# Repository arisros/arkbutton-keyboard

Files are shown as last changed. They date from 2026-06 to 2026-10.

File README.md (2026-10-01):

# ArkButton: split keyboard build

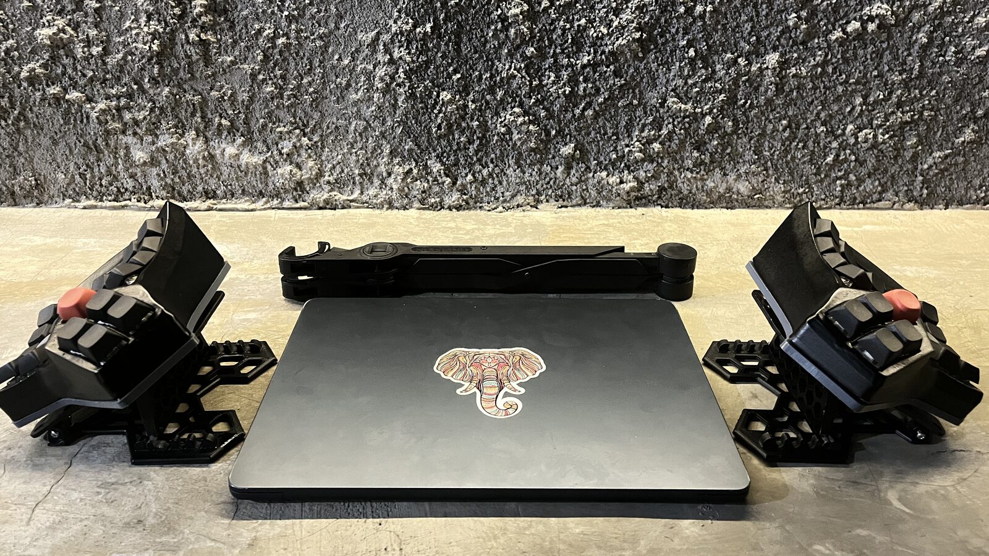
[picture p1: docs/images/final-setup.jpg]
ArkButton on its tenting stands, one half either side of a laptop


Working files for a **handwired wireless split keyboard**: Bastard Keyboards
*Scylla* / *Charybdis* geometry, 24 finger keys + 5 thumb keys per hand
(**58 keys**, the innermost thumb position stays unpopulated), 2× HwThinker Pro
Micro nRF52840 (nice!nano v2 compatible) running ZMK, printed on an Elegoo
Neptune 4 Pro, on an articulated tenting stand.

**Status:** finished in July 2026. The story with photos is in
[`docs/BUILD-LOG.md`](docs/BUILD-LOG.md).

Everything here is **source and notes**. The STL / GCODE / PNG / UF2 output is
deliberately not committed, it is regenerated (see below).

## Specs

| | |
|---|---|
| Keys | 58: 24 finger + 5 thumb per hand |
| Case | Bastard Keyboards Scylla MK2, 5-thumb default, PLA |
| Switches / keycaps | Gateron G Pro Brown, PBT MOA |
| Wiring | handwired matrix, one 1N4148 per switch, soldered direct (no hotswap) |
| Controllers | 2× HwThinker Pro Micro nRF52840 (nice!nano v2 compatible) |
| Firmware | ZMK, config in [arisros/charybdis-wireless-zmk](https://github.com/arisros/charybdis-wireless-zmk) |
| Tenting | Charybdis tenting stand mod (base stand, no wrist pads), 17/21/25/29° notches |
| Printer | Elegoo Neptune 4 Pro (Klipper) |

## Build

<p>
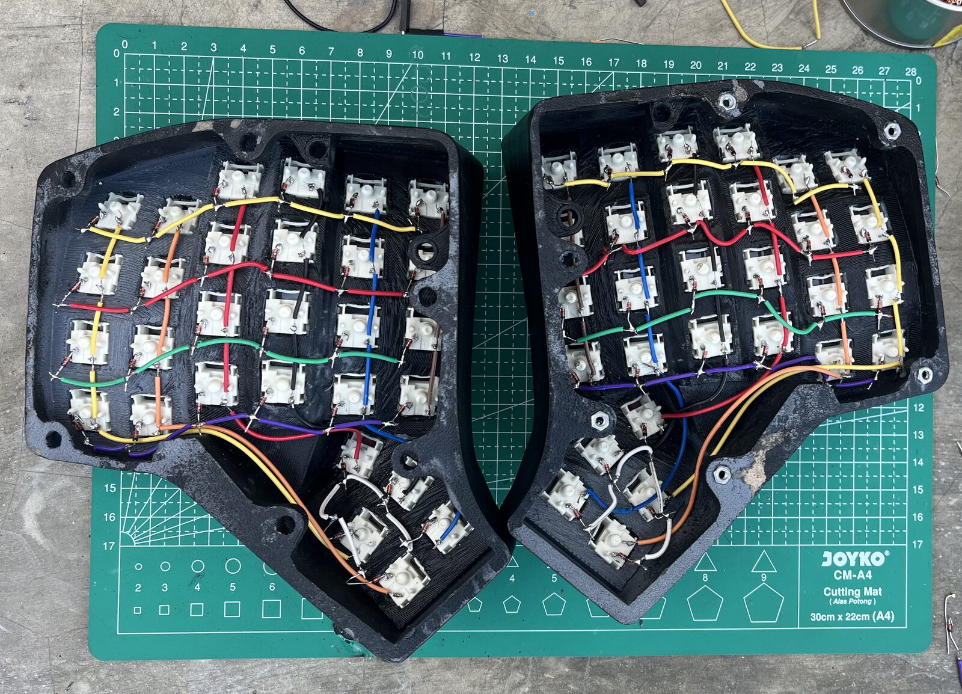
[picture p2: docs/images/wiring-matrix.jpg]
Both halves with the diode matrix wired
  
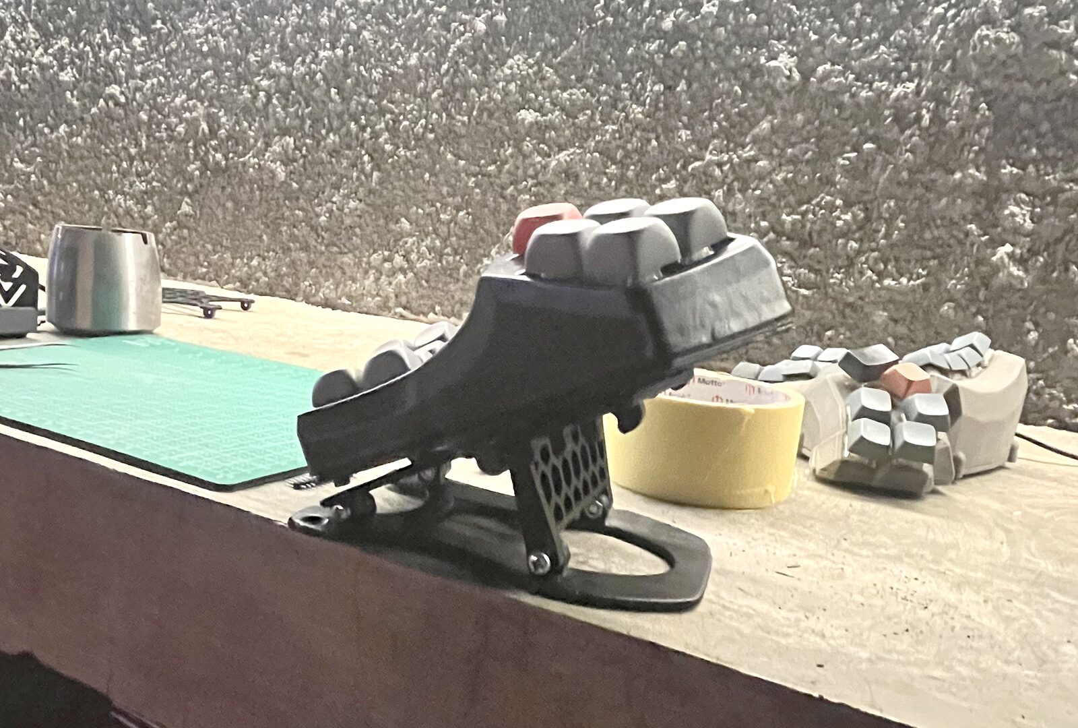
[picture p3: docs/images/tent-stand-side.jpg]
One half on the tenting stand, side view
  
</p>

More photos and the timeline: [`docs/BUILD-LOG.md`](docs/BUILD-LOG.md).

## Layout

| Path | What |
|---|---|
| `docs/` | `BUILD-LOG.md` (dated build timeline) and `images/` (build photos) |
| `PRINT-QUEUE.md` | what to print, in what order, which slicer profile. Includes the verified handedness correction (upstream file names are mirrored) |
| `SHOPPING-LIST.md` / `.csv` | parts, decisions (solder-direct, no hotswap) and what's already bought |
| `preview-*.html` | three.js viewers: `preview.html` (Charybdis 6-thumb + tenting), `preview-tenting.html` (stand + articulated arm), `preview-full-assembly-magnet.html`, `preview-wiring.html` (wiring sheet), `preview-keymap.html` (keymap) |
| `tools/` | the dev-cycle toolkit: build → validate → capture. See `tools/README.md` |
| `tools/tent/` | OpenSCAD sources for the tenting plate / cover / hinge / magnet mount, plus `PRINT-FINDINGS.md` (why the plate must print vertically) |
| `cosmos/` | OpenSCAD sources + viewers for the earlier Cosmos/Dactyl case and its I/O block |
| `firmware/` | `flash` (drop a .uf2 on a nice!nano) and `kbstatus` (Bluetooth state on macOS) |
| `upstream-mods/` | our own sources that live *inside* the gitignored upstream clones, see `upstream-mods/README.md` |

## Setup

The upstream repos are not vendored here (each has its own remote), but the tools
and viewers reference them by path. Restore them with:

```bash
tools/fetch-upstream.sh      # clones Charybdis, Scylla, Cosmos-Keyboards,
                             # dactyl-manuform-keyboard, STL-to-OpenSCAD-Converter
                             # at their pinned commits, then copies upstream-mods/ in
```

Then the normal loop (details in `tools/README.md`):

```bash
node tools/cycle.mjs <target>    # build → validate → capture → summary
node tools/capture.mjs <set…>    # headless multi-view PNGs into tools/captures/
```

If you edit anything *inside* a clone, run `tools/save-mods.sh` before committing,
otherwise the change only exists on this machine.

## Firmware

The ZMK config lives in its own repo: **https://github.com/arisros/charybdis-wireless-zmk**.
Its GitHub Actions build produces the `.uf2` files; download the `firmware` artifact,
unzip into `firmware/`, then:

```bash
firmware/flash left | right | reset
firmware/kbstatus
```

## Not in git

`*.stl` `*.3mf` `*.gcode` `*.uf2`, `out/`, `tools/captures/`, render PNGs, the
upstream clones, and `node_modules/`. All of it is regenerated from what *is* here.

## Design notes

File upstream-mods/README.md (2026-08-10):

# upstream-mods

Source files of *ours* that physically live inside the upstream clones
(`Charybdis/`, `Cosmos-Keyboards/`, `Scylla/`, `dactyl-manuform-keyboard/`).
Those clones are gitignored — they each have their own remote — so anything we
edit or add in there would otherwise exist on this machine only.

The tree here mirrors the path inside the clone exactly:

```
upstream-mods/Cosmos-Keyboards/src/model_gen/userconfig.ts
        ↕
              Cosmos-Keyboards/src/model_gen/userconfig.ts
```

Text sources only (`.scad` / `.ts` / `.mjs` / `.md`). The STLs they produce stay
out of git — regenerate them with `node tools/build.mjs`.

## Two directions

```bash
tools/fetch-upstream.sh   # clone the upstream repos + copy these files INTO them
tools/save-mods.sh        # copy them back OUT of the clones into this repo
```

Run `tools/save-mods.sh` before committing whenever you have been editing inside a
clone, otherwise the change stays untracked in ignored territory.

## What's here

| Path | What it is |
|---|---|
| `Cosmos-Keyboards/src/model_gen/userconfig.ts` | the Cosmos case definition — the source every `cosmos/*.stl` is generated from |
| `Cosmos-Keyboards/src/model_gen/mesh-split.mjs`, `gen-*.ts` | export/split helpers driven by `tools/build.mjs` |
| `Cosmos-Keyboards/src/lib/worker/{api.ts,pro-patch/rounded.ts}` | local patches to upstream worker code |
| `Charybdis/files/mods/trackball-plug-6key/` | trackball-hole plug + 6-thumb demo CAD |
| `Charybdis/files/mods/tenting-stand-with-wrist-pads/TENTING-COVER-FUSION-GUIDE.md` | notes on grafting the tenting cover |
| `Scylla/files/MK2/` | 6-thumb variant, SuperMini cradle and flat holder |
| `dactyl-manuform-keyboard/cosmos/` | tent stand / module / MCU housing OpenSCAD |

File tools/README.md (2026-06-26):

# Dev-cycle toolkit

One fast loop for iterating the keyboard + tent stand:
**develop → `cycle` → review → improve → repeat.**

## The loop
```bash
node tools/cycle.mjs <target>     # build(target) → validate → capture → summary
```
1. **develop** — edit a param (`Cosmos-Keyboards/src/model_gen/userconfig.ts`,
   `…/mesh-split.mjs`, or `dactyl-manuform-keyboard/cosmos/tent_stand.scad`).
2. **cycle** — regenerates only what the change needs, checks geometry, renders views.
3. **review** — read `tools/validate-report.json` (regressions auto-caught) +
   `tools/captures/*.png` + the live viewer at http://localhost:8011/viewer.html.
4. **improve** — adjust, run cycle again.

`target` ∈ `block | case | holder | plate | stand | labels | fullcase | all`
(what to rebuild). Default `all`.

## Tools (each runnable alone)
| tool | what |
|---|---|
| `node tools/build.mjs <target…>` | regenerate STLs per the dependency graph (bun gen-*.ts, node mesh-split.mjs, OpenSCAD stand export) |
| `node tools/validate.mjs` | watertight + non-empty + bbox-range checks vs `spec.json`; writes `validate-report.json`, non-zero exit on FAIL |
| `node tools/capture.mjs [set…]` | headless three.js multi-view PNGs → `captures/<set>-<view>.png` (reliable cameras; sets: assembly case stand io thumb) |
| `tools/stl.mjs` | shared lib: `bbox()`, `loadManifold()`, `metrics()` (binary + ASCII STL) |
| `tools/spec.json` | per-part assertions (edit to tighten as the design settles) |

## What each change needs rebuilt
- `userconfig.ts` (case/thumb) → `cycle case` (then `plate`+`stand` if footprint moved)
- `mesh-split.mjs` (I/O window/holes) → `cycle block`
- `tent_stand.scad` (hinge/leg/lock) → `cycle stand`

## Notes
- Capture renders the **exported STLs** through three.js (Z-up, explicit cameras) —
  this is the reliable replacement for OpenSCAD CLI `--camera`.
- OpenSCAD exports **ASCII** STL; the rest are binary — `stl.mjs` handles both.
- Keep `viewer.html`'s duplicated stand constants (HINGE_X, PIVOT_X, LEG_LEN,
  TB, TC, SLOT_XS, prop dims) in sync with `tent_stand.scad` by hand.

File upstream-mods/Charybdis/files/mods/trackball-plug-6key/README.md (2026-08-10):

# trackball-plug-6key

Drop-in plug for the Charybdis 4x6 that **fills the 34 mm trackball cavity and mounts the
6th thumb switch** (MX Gateron hotswap), turning the stock 5-key thumb into a 6-key thumb
without touching the main case STL.

## Files
- `plug.scad` — parametric source (right hand). Tune via the params block at the top.
- `plug_right.stl` / `plug_left.stl` — exported, validated (watertight, bbox 45.6×45.5×21 mm).
- `plug_left.scad` — X-mirror wrapper of the right STL (fixes hotswap/LED orientation for the left half).

## How it fits (grounded in the stock parts)
- Body Ø **41.7 mm** drops into the case's **42 mm** trackball bore; flange Ø **45.6 mm** rests on the rim
  (mimics `../../4x6/adapter_v4_v4_top.stl`). Depth into bore ~18 mm; cavity is ~20 mm deep.
- The switch plate is **recessed 4 mm** and **counter-rotated ~14°** so the cap lands at **~15° tilt**
  (the cavity opening itself is 29° from horizontal). The flange notch marks the **user/thumb side**.

## ⚠️ First-print checklist (this is the one thing to verify)
1. Print **one** `plug_right.stl`, dry-fit into your printed `charybdis_v4_247_right.stl`.
2. Check: body seats in the bore, flange sits flush, an MX switch + keycap clears the wall.
3. **Feel the ~15° thumb angle.** If it leans the wrong way / too steep, flip the sign of `tilt_corr`
   in `plug.scad` (or adjust the value) and re-export — only the small plug reprints, not the case.
4. The MX **hotswap socket pocket** (pin holes + slide-in mouth) is parametric and may need a tweak
   (`hs_depth`, `hs_w`, `pin_d`) for a snug Gateron socket — adjust after the fit is confirmed.

## Re-export after editing params
```
/Applications/OpenSCAD.app/Contents/MacOS/OpenSCAD -o plug_right.stl plug.scad
/Applications/OpenSCAD.app/Contents/MacOS/OpenSCAD -o plug_left.stl  plug_left.scad
```
Validate: `node -e` with `metrics()` from `../../../../tools/stl.mjs` (watertight + bbox check).

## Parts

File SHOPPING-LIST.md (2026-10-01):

# Shopping List: Scylla/Charybdis Wireless Handwired (Neptune 4 build)

> Historical working note. The build was finished in July 2026 (see `docs/BUILD-LOG.md`); checkboxes below are as of the last edit and were not all updated after purchase.

Build = **handwired wireless** split keyboard (**2× HwThinker Pro Micro nRF52840**, nice!nano v2 compatible, + ZMK), 24 finger + **5 thumb** per hand = **29 keys/hand, 58 total**. (The thumb row has 6 matrix positions but the innermost one on each hand has no switch.) All links are **Tokopedia**, prioritising **best sellers that are in stock**.

> 🔩 **Assembly decision: SOLDER DIRECT (no hotswap).** Priority = **DURABILITY**. Diodes + wire are soldered permanently to the switch legs: fewest failure points, no socket contacts that can loosen or oxidise over time. Gateron G Pro switches are rated ~50M clicks → swapping would almost never be used. **Gateron hotswap sockets CANCELLED** (not paid yet). The Scylla case is also confirmed (render) to have **no socket pockets**, it is meant for a PCB.

> ⚠️ Research note: Tokopedia product pages block automated fetches, so **price / units sold / rating are not 100% verified** and **product URLs may not be live** (curl to tokopedia.com = fully blocked from this machine). What DEFINITELY works = the `/find/` search links. Before checkout: open the link → check stock → sort by **Terlaris** (best selling) + rating ≥4.8.

## ✅ Already bought (skip)
- [x] MX switches, Gateron G Pro Brown
- [x] PBT MOA keycaps

## ❌ Cancelled (not buying)
- [x] ~~Gateron hotswap sockets~~ → solder direct for durability (not paid yet, safe)
- [x] ~~Amoeba PCB~~ → not needed (no hotswap)

## 🛠️ Durability notes (what makes it last)
- **M3 heat-set inserts** (item 8): the case threads do not strip when it is opened and closed many times.
- **Strain relief** on the cables into the nice!nano (glue / hot glue where the cable enters): the board's solder joints do not snap when pulled.
- Solder cleanly with **no-clean flux** (item 13); the diode + wire joints on the switch pins must be full & shiny.
- Diodes + enamel wire = permanent joints, the most durable over the years.

---

## 🛒 To buy

### 1. Controller: **HwThinker Pro Micro nRF52840** (nice!nano v2 compatible) · **Qty 2** (left+right)
- [x] **In use (both):** Pro Micro NRF52840 BLE 5.0, *HwThinker*
  https://www.tokopedia.com/hwthinker/pro-micro-nrf52840-promicro-nrf52-nano-33-ble-5-0-bluetooth-nice-nano
- [ ] Alternative: Supermini NRF52840 Dev Board (compatible nice!Nano V2.0), *Metro Moda*
  https://www.tokopedia.com/metro-moda/supermini-nrf52840-development-board-compatible-with-nice-nano-v2-0
- Search/compare: https://www.tokopedia.com/find/nrf52840 (keyword: `pro micro nrf52840 nice nano`)
- ⚠️ **This clone REQUIRES the clock fix.** The HwThinker Pro Micro nRF52840 has no 32.768kHz crystal, which nice!nano v2 assumes → BLE split link times out, right hand dead. Fix: `CONFIG_CLOCK_CONTROL_NRF_K32SRC_RC=y` in `charybdis_handwired.conf` (forces the internal RC oscillator). Compile ZMK with the `nice!nano v2` profile.
- ℹ️ Pin **P0.22 is dead** as GPIO (QSPI flash) on this board → Col1 moved to P0.31 (already done in the dtsi). P0.20/P0.24 are still used & safe on this board.

### 2. LiPo battery 3.7V · **Qty 2**
- [ ] **Primary (plug-and-play nice!nano):** 6pcs 3.7V 110mAh **301230** JST PH 2.0mm "for nice nano", *Penggesu*
  https://www.tokopedia.com/penggesu/6pcs-lot-3-7v-110mah-301230-lithium-polymer-jst-ph-2-0mm-for-nice-nano-or-wireless-keyboard-bluetooth-headset-3d-recording-pen
  → 1 lot (6pcs) is enough for 2 boards + spares. Thin (3mm), the safest fit in the case.
- [ ] Larger capacity (lasts longer, 4mm): 3.7V 500mAh **401230**, *osakasparepart*
  https://www.tokopedia.com/osakasparepart/baterai-lithium-ion-polymer-lipo-3-7v-500mah-401230
- Search other sizes (502030 etc.): https://www.tokopedia.com/find/502030
- ✅ nice!nano uses **JST PH 2.0mm**: the primary battery above already has a PH2.0 connector, **just plug it in**.

### 3. JST PH 2.0 connector (optional, if the battery lead needs replacing/extending)
- [ ] JST PH 2.0mm 2-pin connector + lead, search: https://www.tokopedia.com/find/jst-ph-2.0-2pin
- ❗ JST **1.25mm** is probably **NOT needed** (nice!nano = 2.0mm). Buy 1.25 only if your board specifically uses it.

### 4. Slide switch (battery on/off) · **Qty 2**
- [ ] **Primary:** SS12D00 Saklar Geser Mini SPDT 3 Pin, *Gudang Listrik Pontianak*
  https://www.tokopedia.com/gudanglistrikpontianak/ss12d00-saklar-geser-mini-slide-switch-mini-on-on-3-pin-2-way-spdt
- [ ] Backup: SS12D00 G4 4mm SPDT, *TechnoHance*
  https://www.tokopedia.com/technohance/saklar-geser-kecil-3-pin-spdt-1p2t-sorong-toggle-switch-ss12d00-g4-4mm
- Search: https://www.tokopedia.com/find/switch-spdt-3-pin

### 5. Reset push button (tactile) · **Qty 2** (the cradle has a reset holder)
- [ ] **Primary:** Tactile Switch 6x6x4.3mm, *DutaPart*
  https://www.tokopedia.com/dutapart/tactile-switch-push-button-6x6x4-3-mm-6x6-x-4-3mm-pcb-mount-mini-micro
- [ ] Backup: Tactile Switch SMD 6x6, *Peony Glodok*
  https://www.tokopedia.com/peonyglodok/tactile-switch-push-button-smd-6x6-2p-4p-pin-tombol-micro-momentary-4p-6x6x4-3-tanpa-bubble
- Search: https://www.tokopedia.com/find/tactile-switch-push-button-6x6
- ℹ️ Check the pocket dimensions in `supermini_cradle.scad` (reset hole ~5×4.5mm) and pick a plunger height that fits.

### 6. 1N4148 diodes · **~92 pieces** (1 per switch) → buy 2 packs of 100
- [ ] **Primary (best seller, 5.0/57 reviews, ~Rp9,500):** 100pcs Dioda 1N4148, *sarahelektronik*
  https://www.tokopedia.com/sarahelektronik/100pcs-dioda-1n4148-in4148
- [ ] Backup: 100pcs 1N4148, *Latronika*
  https://www.tokopedia.com/latronika/100pcs-dioda-1n4148-1n-4148-rectifier-diode-in4148-in-4148-100-buah-1729816698188432867
- Search: https://www.tokopedia.com/find/dioda-1n4148

### 7. Enamelled wire 0.25-0.3mm (~AWG30) for handwiring the matrix · **~15m/hand**
- [ ] **Primary (big wire shop, 5k+ sold):** Kawat Email Tembaga 0.3mm /meter, *HARDA JAYA*
  https://www.tokopedia.com/040489/kawat-email-tembaga-0-3mm-per-1meter-meteran-0-3-mm-per-1m
- [ ] Thinner (0.25mm ≈ AWG30): *ELECHOUSE ID*
  https://www.tokopedia.com/elechouse/kawat-0-25mm-0-25-tembaga-email-enamel-1-meter
- Search: https://www.tokopedia.com/find/kawat-email-tembaga
- ℹ️ Enamelled = coated, the ends must be scraped/burnt before soldering. Buy ~10-15m per hand. (Easier alternative: insulated single-core wire / kynar 30AWG.)

### 8. M3 heat-set inserts (brass) to fix the plate to the case
- [ ] **Primary:** Brass Heat Insert M3 30pcs (3D print), *IndoCart*
  https://www.tokopedia.com/indocart/3d-printer-tools-compatible-brass-heat-insert-nuts-double-twill-knurled-injection-copper-thread-inserts-x-30pcs-173165609381714486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
- [ ] Backup (pick M3x5x4): *Cipta Karya 3D*
  https://www.tokopedia.com/ciptakarya3d/brass-hot-melt-thread-inserts-nut-m2-m2-5-m3-m4-m5-m6-m8-double-twill-knurled-standar-internasional-gb-1pcs-173067940859671488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
- Search: https://www.tokopedia.com/find/heat-set-insert-m3 · ideal size **M3 OD4-5 / L4-5mm**

### 9. M3 bolts (socket cap, 6-10mm)
- [ ] **Primary (many lengths in 1 listing):** Baut L M3 3-50mm, *salsaa-sttrre*
  https://www.tokopedia.com/salsaa-sttrre/baut-l-m3-m4-m5-3mm-4mm-5mm-6mm-8mm-10mm-14mm-16mm-20mm-25mm-30mm-m3-35mm-497db
- [ ] SUS304 socket cap M3x12, pack of 10, *BAUTMUR INDONESIA*
  https://www.tokopedia.com/bautmurindonesia/allen-bolt-baut-l-sus304-socket-cap-screw-m3x12-isi-10-pcs
- Search: https://www.tokopedia.com/find/sekrup-m3 · suggested **M3x6 to M3x10** to go into the inserts

### 10. Rubber feet / bumpons (anti-slip under the keyboard)
- [ ] **Primary (keyboard specific):** Rubber Feet Mechanical Keyboard, *SquarePlay*
  https://www.tokopedia.com/squareplay/rubber-feet-kaki-karet-mechanical-keyboard
- [ ] 10pcs 3M Self Adhesive Rubber Feet, *HERZ Garage*
  https://www.tokopedia.com/herzhz/10-pcs-3m-self-adhesive-rubber-feet-kaki-karet
- Search: https://www.tokopedia.com/find/rubber-feet-3m

### 11. USB-C DATA cable (firmware flashing, not charge-only)
- [ ] **Primary (10k+ sold, official):** UGREEN Kabel Data USB→Type-C 3A, *UGREEN Official Store*
  https://www.tokopedia.com/ugreenofficialstore/kabel-data-usb-type-c-ugreen-for-samsung-oppo-vivo-fast-charging-3a
- Search (pick one that says "data 480Mbps"): https://www.tokopedia.com/find/kabel-data-type-c
- ⚠️ Make sure the board port = USB-C (many SuperMini clones are USB-C). Avoid "charge only" cables.

### 12. Solder wire 0.6mm: **REQUIRED (home stock is nearly out)**
- [ ] **Primary:** Mechanic Timah Solder 0.6mm TY-V866, *PGC Sparepart*
  https://www.tokopedia.com/pgc-sparepart/mechanic-original-kawat-timah-solder-gulung-0-6mm-ty-v866-wire-roll
- Best-seller alternative (Paragon, pick 0.6mm): https://www.tokopedia.com/find/timah-solder-paragon
- ℹ️ Pick rosin/flux core 0.6mm; 60/40 leaded is the easiest. ~46 switches × (diode+wire) needs a fair amount, buy ≥1 roll.

### 12b. Soldering tools (owned: **original MASDA 40W, but old**)
- The MASDA 40W stick iron is **still enough** for through-hole handwiring (diodes/wire). But an old tip is usually oxidised → solder will not wet = brittle joints (the enemy of "durable").
- [ ] **Replacement tip** (pointed, fits MASDA 40W), search: https://www.tokopedia.com/find/mata-solder-40w
- [ ] **Tip cleaner** (brass wool / sponge), search: https://www.tokopedia.com/find/pembersih-mata-solder
- [ ] *(Optional, upgrade for precision & durability)* **Temperature-controlled soldering station** (e.g. 936/8586): much nicer for 46+ fine joints. Search: https://www.tokopedia.com/find/solder-station-suhu
- [ ] *(Optional)* **Solder sucker / solder wick** to fix soldering mistakes. Search: https://www.tokopedia.com/find/penyedot-timah-solder

### 13. Solder flux (no-clean / RMA for PCBs)
- [ ] Flux Pasta Solder 35ml (PCB & components), *fanila shop*
  https://www.tokopedia.com/fanila-shop-779/flux-pasta-solder-35ml-untuk-solder-komponen-pcb-dan-stainless-tembaga-timah-logam-1730829385622718260
- Search (recommended: YAXUN / Ezren RMA-616 no-clean): https://www.tokopedia.com/find/flux-solder
- ⚠️ Avoid plumber's flux paste, which is acidic/corrosive. Pick **RMA / no-clean**.

---

## Quantity notes
| Item | Qty | Reason |
|---|---|---|
| Controller | 2 | left + right |
| LiPo battery | 2 | 1 per half (buying the 6pcs lot = spares) |
| Slide switch | 2 | battery on/off per half |
| Reset button | 2 | reset holder in the cradle |
| 1N4148 diodes | ~92 (buy 200) | 1/switch + spares |
| Enamelled wire | ~30m | ~15m/hand for the matrix |
| M3 heat-set inserts | as many as the plate has holes | check the case |
| M3 bolts | to match the inserts | 6-10mm |

---

## 🧰 PLA printer maintenance tools (reusable, always in use)
> `/find/` links definitely work; product links = candidates from search results (not verified).

### M1. Nozzle cleaning needles 0.35-0.4mm
- [ ] Nozzle Cleaner Needle kit 10pcs (DY11), *Hardware Solutions*
  https://www.tokopedia.com/hardwaresolutions/jarum-pembersih-nozzle-3d-printer-cleaning-needle-10pcs-dy11
- Search: https://www.tokopedia.com/find/jarum-pembersih-nozzle
- ℹ️ Use 0.35mm for a 0.4 nozzle (not exactly 0.4, so the hole does not widen).

### M2. Brass brush (for cleaning the nozzle, not steel)
- [ ] 12pcs Sikat Kawat Kuningan gagang lengkung 3D printer, *K-Dunk*
  https://www.tokopedia.com/k-dunk/12-pcs-sikat-kawat-tembaga-kuningan-gagang-lengkung-3d-printer
- Search: https://www.tokopedia.com/find/sikat-kuningan-nozzle

### M3. Scraper / spatula for lifting prints
- Search (many stainless + rubber handle options): https://www.tokopedia.com/find/scraper-3d-print · https://www.tokopedia.com/find/spatula-scraper

### M4. ESD tweezers (1 straight + 1 angled)
- [ ] Set Pinset ESD anti-static, *Pi Toserba*
  https://www.tokopedia.com/pitoserba/pinset-esd-series-anti-static-tweezers-untuk-jepit-komponen-smd-dll-paket-6-pcs-5ebe4
- Search: https://www.tokopedia.com/find/pinset-elektronik-anti-static
- 💡 The angled tweezers are also useful for handwiring (holding diodes/wire).

### M5. Flush cutter (cutting supports + filament)
- [ ] Nipper model kit (Plato/Xuron), *mechaniSTORE*
  https://www.tokopedia.com/mechanistore/tang-potong-xuron-nipper-for-gundam-model-kit
- Search: https://www.tokopedia.com/find/tang-potong-gundam

### M6. Cleaning / cold-pull filament (clears leftover filament from the nozzle)
- Search: https://www.tokopedia.com/find/cleaning-filament-1.75mm · https://www.tokopedia.com/find/esun-cleaning-filament

### M7. Isopropyl Alcohol (IPA) 99% for cleaning the PEI bed
- [ ] IPA 99% 1 Liter, *PAChemical*
  https://www.tokopedia.com/pachemicals/isopropyl-alcohol-isopropyl-alkohol-ipa-99-1-liter
- Search: https://www.tokopedia.com/find/isopropyl-alcohol-99
- ℹ️ Spray onto a cloth first, not straight onto the bed. (Toolkit §2/§6 also uses an IPA wipe between prints.)

---

## ✨ Finishing, for a smooth surface (PLA)
Order of work: **fill holes with putty → filler primer → fine wet sanding → paint → clear coat**.

### F1. Sandpaper set, grit 400-2000 (wet sanding)
- [ ] Amplas Duco Waterproof grit 400-3000 (buy per grit: 400/600/800/1000/1500/2000), *wilonastore2015*
  https://www.tokopedia.com/wilonastore2015/amplas-duco-grit-400-600-800-1000-1200-1500-2000-2500-3000-sand-paper-waterproof-kertas-lembaran-amplas-basah-kering-halus-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
- Long-lasting brand (Germany): MATADOR, https://www.tokopedia.com/jababekateknikatama/matador-amplas-kertas-grit-400-600-800-1000-1500-2000-2500-3000-kertas-amplas-waterproof-merk-matador-germany-173189210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
- Search: https://www.tokopedia.com/find/amplas-duco

### F2. Sanding block (keeps the surface flat)
- [ ] DSPIAE Sanding Block, *wahkhilaf*
  https://www.tokopedia.com/wahkhilaf/sanding-block-amplas-blok-pegangan-handle-datar-lurus-dspiae-curved
- Search: https://www.tokopedia.com/find/sanding-block

### F3. Putty (covers layer lines & holes)
- [ ] Tamiya Putty Basic 32g (easy to sand, for plastic), *gerberas-corner*
  https://www.tokopedia.com/gerberas-corner/tamiya-putty-basic-type-dempul-gundam-model-kit-cat-kuas-airbrush
- Large holes: Alteco EpoPutty / Tamiya Epoxy Putty
- Search: https://www.tokopedia.com/find/tamiya-putty · https://www.tokopedia.com/find/epoxy-putty

### F4. Spray filler primer / surfacer (covers layer lines before paint), **important**
- [ ] Diton Putty Primer 1K 300mL (5k+ sold), search: https://www.tokopedia.com/find/diton-putty-primer
- Modeller favourite: Samurai Plastic Primer, https://www.tokopedia.com/find/samurai-paint-plastic-primer
- Search: https://www.tokopedia.com/find/filler-primer

### F5. Spray paint (base colour; good brands: Pylox/Samurai/Diton)
- [ ] Pylox/Pilox (e.g. matte black), *Saban Rame*
  https://www.tokopedia.com/sabanrame/pylox-hitam-kilap-hitam-doff-cat-semprot
- Search: https://www.tokopedia.com/find/cat-semprot-pylox

### F6. Clear coat / varnish (final layer; **matte** suits a keyboard case)
- [ ] Pylox Magic Clear Doff 300cc, *TSM Shops*
  https://www.tokopedia.com/tsm-shops/cat-semprot-pilox-pilok-magic-clear-doff-pernis-doff-dop-110-300cc
- Search: https://www.tokopedia.com/find/pylox-clear-doff

### F7. Masking tape (optional, to mask areas while painting)
- Search: https://www.tokopedia.com/find/masking-tape · precision: https://www.tokopedia.com/find/tamiya-masking-tape

> 💡 Tips: sand **wet**, coarse→fine in order (400→600→800→1000→1500→2000), do not skip grits, stick the paper to a sanding block so it stays flat. Prime first so layer defects show up. Buy primer+paint+clear from **1 shop** to save on shipping.

---

## 🦵 Tenting stand hardware (base stand, no wrist pad)
Modular adjustable stand (`Charybdis/files/mods/tenting-stand-with-wrist-pads/`). The parts are already prepped in `tools/tent/`.
- [ ] **M4 bolts, length ≥14mm × 8**, search: https://www.tokopedia.com/find/baut-m4-15mm (socket cap looks neater)
- [ ] **M4 nuts × 8**, search: https://www.tokopedia.com/find/mur-m4
- ℹ️ If you want the **gel wrist pad** later: that needs 12 sets of M4 + 2 gel mouse pads (`https://www.tokopedia.com/find/gel-mouse-pad-wrist`).

## Not needed yet (postponed)
- Battery holder / cradle mount to the case: later, once the keyboard is functional.
- JST 1.25mm: probably not used (nice!nano = PH2.0).

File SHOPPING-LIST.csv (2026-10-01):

No | Category | Item | Qty | Priority | Link | Notes
1 | Electronics | HwThinker Pro Micro nRF52840 (compatible nice!Nano V2.0) | 2 | Required | https://www.tokopedia.com/hwthinker/pro-micro-nrf52840-promicro-nrf52-nano-33-ble-5-0-bluetooth-nice-nano | Left+right (both in use). Clone without a 32kHz crystal -> REQUIRES CONFIG_CLOCK_CONTROL_NRF_K32SRC_RC=y (otherwise the right hand is dead). P0.22 dead (QSPI) -> Col1 moved to P0.31. Compile ZMK with the nice!nano v2 profile
2 | Electronics | LiPo battery 3.7V 110mAh 301230 JST PH2.0 (lot of 6pcs) | 1 lot | Required | https://www.tokopedia.com/penggesu/6pcs-lot-3-7v-110mah-301230-lithium-polymer-jst-ph-2-0mm-for-nice-nano-or-wireless-keyboard-bluetooth-headset-3d-recording-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 | 1 lot is enough for 2 boards + spares. Thin 3mm. PH2.0 connector just plugs in
3 | Electronics | Slide switch SS12D00 SPDT 3pin (battery on/off) | 2 | Required | https://www.tokopedia.com/gudanglistrikpontianak/ss12d00-saklar-geser-mini-slide-switch-mini-on-on-3-pin-2-way-spdt | 1 per half
4 | Electronics | Tactile reset push button 6x6x4.3mm | 2 | Required | https://www.tokopedia.com/dutapart/tactile-switch-push-button-6x6x4-3-mm-6x6-x-4-3mm-pcb-mount-mini-micro | Reset holder in the cradle. Check pocket ~5x4.5mm
5 | Electronics | 1N4148 diodes (100pcs/pack) | 2 pack | Required | https://www.tokopedia.com/sarahelektronik/100pcs-dioda-1n4148-in4148 | ~92 used (1/switch) + spares
6 | Handwiring | Enamelled copper wire 0.3mm (per meter) | 30 m | Required | https://www.tokopedia.com/040489/kawat-email-tembaga-0-3mm-per-1meter-meteran-0-3-mm-per-1m | ~15m/hand. Scrape/burn the ends before soldering
7 | Hardware | M3 brass heat-set inserts (30pcs) | 1 pack | Required | https://www.tokopedia.com/indocart/3d-printer-tools-compatible-brass-heat-insert-nuts-double-twill-knurled-injection-copper-thread-inserts-x-30pcs-17316560938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 | Fixes the plate to the case. Size M3 OD4-5 L4-5mm
8 | Hardware | M3 socket cap bolts 6-10mm | 1 set | Required | https://www.tokopedia.com/salsaa-sttrre/baut-l-m3-m4-m5-3mm-4mm-5mm-6mm-8mm-10mm-14mm-16mm-20mm-25mm-30mm-m3-35mm-497db | Go into the inserts. M3x6-M3x10
9 | Tent-Magnet | Neodymium magnet N52 diameter 8mm x 1.5mm | 24 pcs | Required | https://www.tokopedia.com/find/magnet-neodymium-8mm | NEW: tent-joint magnets. 5 pockets/plate + 5/cover = 10/half x2 = 20 + spares. Make sure the size is 8x1.5mm N52
10 | Tent-Hardware | M4 socket cap bolts length >=14mm | 8 pcs | Required | https://www.tokopedia.com/find/baut-m4-15mm | Stand mechanism (base+arm hinge). Not the keyboard joint (that is the magnets)
11 | Tent-Hardware | M4 nuts | 8 pcs | Required | https://www.tokopedia.com/find/mur-m4 | Pair with the stand M4 bolts
12 | Electronics | USB-C data cable 3A (data 480Mbps not charge-only) | 1 | Required | https://www.tokopedia.com/ugreenofficialstore/kabel-data-usb-type-c-ugreen-for-samsung-oppo-vivo-fast-charging-3a | For flashing firmware. Make sure the board port is USB-C
13 | Solder | Solder wire 0.6mm rosin/flux core 60/40 | 1 roll | Required | https://www.tokopedia.com/pgc-sparepart/mechanic-original-kawat-timah-solder-gulung-0-6mm-ty-v866-wire-roll | Home stock nearly out. Buy >=1 roll
14 | Solder | Replacement 40W soldering tip (pointed) + tip cleaner | 1 set | Required | https://www.tokopedia.com/find/mata-solder-40w | MASDA 40W old tip is oxidised. Tip cleaner: /find/pembersih-mata-solder
15 | Solder | No-clean/RMA flux paste | 1 | Required | https://www.tokopedia.com/fanila-shop-779/flux-pasta-solder-35ml-untuk-solder-komponen-pcb-dan-stainless-tembaga-timah-timah-logam-1730829385622718260 | Avoid acidic/corrosive flux. Pick RMA/no-clean
16 | Keyboard | Rubber feet 3M self-adhesive | 1 pack | Required | https://www.tokopedia.com/herzhz/10-pcs-3m-self-adhesive-rubber-feet-kaki-karet | Anti-slip + rubber foot recess in cover_magfeet (diameter 8)
17 | Printer-Maint | Nozzle cleaning needles 0.35mm (kit of 10pcs) | 1 | Optional | https://www.tokopedia.com/hardwaresolutions/jarum-pembersih-nozzle-3d-printer-cleaning-needle-10pcs-dy11 | 0.35 for a 0.4 nozzle
18 | Printer-Maint | Brass nozzle brush | 1 | Optional | https://www.tokopedia.com/k-dunk/12-pcs-sikat-kawat-tembaga-kuningan-gagang-lengkung-3d-printer | Not a steel brush
19 | Printer-Maint | Scraper/spatula for lifting prints | 1 | Optional | https://www.tokopedia.com/find/scraper-3d-print
20 | Printer-Maint | ESD tweezers (straight+angled) | 1 set | Optional | https://www.tokopedia.com/pitoserba/pinset-esd-series-anti-static-tweezers-untuk-jepit-komponen-smd-dll-paket-6-pcs-5ebe4 | Also useful for handwiring
21 | Printer-Maint | Flush cutter | 1 | Optional | https://www.tokopedia.com/mechanistore/tang-potong-xuron-nipper-for-gundam-model-kit | Cuts supports+filament
22 | Printer-Maint | Cleaning/cold-pull filament 1.75mm | 1 | Optional | https://www.tokopedia.com/find/cleaning-filament-1.75mm | Clears leftover filament from the nozzle
23 | Printer-Maint | Isopropyl Alcohol (IPA) 99% 1L | 1 | Optional | https://www.tokopedia.com/pachemicals/isopropyl-alcohol-isopropyl-alkohol-ipa-99-1-liter | Cleans the PEI bed. Spray onto a cloth first
24 | Finishing | Waterproof sandpaper grit 400-2000 | 1 set | Optional | https://www.tokopedia.com/wilonastore2015/amplas-duco-grit-400-600-800-1000-1200-1500-2000-2500-3000-sand-paper-waterproof-kertas-lembaran-amplas-basah-kering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 | Wet sanding coarse->fine in order
25 | Finishing | Sanding block | 1 | Optional | https://www.tokopedia.com/wahkhilaf/sanding-block-amplas-blok-pegangan-handle-datar-lurus-dspiae-curved | Keeps the surface flat
26 | Finishing | Tamiya Putty Basic 32g | 1 | Optional | https://www.tokopedia.com/gerberas-corner/tamiya-putty-basic-type-dempul-gundam-model-kit-cat-kuas-airbrush | Covers layer lines
27 | Finishing | Spray filler primer/surfacer | 1 | Optional | https://www.tokopedia.com/find/diton-putty-primer | Covers layer lines before paint
28 | Finishing | Pylox spray paint (base colour) | 1 | Optional | https://www.tokopedia.com/sabanrame/pylox-hitam-kilap-hitam-doff-cat-semprot
29 | Finishing | Clear coat Pylox Magic Clear Doff 300cc | 1 | Optional | https://www.tokopedia.com/tsm-shops/cat-semprot-pilox-pilok-magic-clear-doff-pernis-doff-dop-110-300cc | Matte suits the case

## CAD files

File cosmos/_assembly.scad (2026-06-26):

// Block installed in the bowl (in place, no explode).
color([0.6,0.6,0.62]) import("case_main.stl");
color([1,0.55,0.05]) import("block.scad");
color([0.2,0.7,0.3]) translate([0,0,-3.2]) import("cosmotyl-plateright.stl");

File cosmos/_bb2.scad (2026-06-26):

color([0.6,0.6,0.62]) import("case_main.stl");
color([1,0.5,0.05]) import("block_panel.stl");
color([0.2,0.5,1]) import("holder.stl");

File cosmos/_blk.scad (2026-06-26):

color([1,0.5,0.05]) import("block.stl");

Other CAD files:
cosmos/_bb.scad
cosmos/_block_parts.scad
cosmos/_cm.scad
cosmos/_front.scad
cosmos/_holder_ax.scad
cosmos/_main_only.scad
cosmos/_platechk.scad
cosmos/_preview.scad
cosmos/_slice.scad
cosmos/_split_axes.scad
cosmos/_split_preview.scad
cosmos/_split_result.scad
cosmos/block.scad
cosmos/case_outline.scad
cosmos/split_mesh.scad
tools/tent/_adjchk.scad
tools/tent/_asm.scad
tools/tent/_asm2.scad
tools/tent/_asmchk.scad
tools/tent/_basebot.scad
tools/tent/_chk.scad
tools/tent/_cm.scad
tools/tent/_cmp.scad
tools/tent/_cover_mod.scad
tools/tent/_dep.scad
tools/tent/_fin.scad
tools/tent/_fin2.scad
tools/tent/_flat2_cover.scad
tools/tent/_flat2_intb.scad
tools/tent/_flat_cover.scad
tools/tent/_flat_intb.scad
tools/tent/_kbh.scad
tools/tent/_kbonly.scad
tools/tent/_kn.scad
tools/tent/_kz.scad
tools/tent/_mL.scad
tools/tent/_mL2.scad
tools/tent/_mLp.scad
tools/tent/_mag_mk.scad
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

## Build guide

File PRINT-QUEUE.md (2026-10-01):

# Print Queue: Scylla wireless build (Neptune 4 Pro)

> Historical working note. The build was finished in July 2026 (see `docs/BUILD-LOG.md`); statuses below are as of the last edit during printing.

Final functional keyboard = **Scylla 5-thumb default** (no case mods) + handwired wireless.
Print **one part at a time** (toolkit §4). Slicer must emit `gcode_flavor=klipper`.
Slice via: `python3 ~/Documents/neptune4-print-toolkit/scripts/slice.py --stl <file> --orient 1 --process <profile>`
(slice.py injects fresh bed mesh + Z offset automatically).

All files watertight ✓. Bed 235×235×280, everything fits.

> ⚠️ **HANDEDNESS CORRECTION (2026-06-30): the file naming in the upstream repo is SWAPPED** (verified: render comparison against Charybdis `_right` + plate IoU). What is in the repo:
> - `scylla_v3_36.stl` & `supermini_cradle.stl` = **LEFT** → RIGHT hand = **mirror X**.
> - `..._plate_right.stl` = actually the **LEFT plate**; `..._plate_left.stl` = actually the **RIGHT plate**.
> The "File" column below is already corrected to the real hand. Mirrors are made via `tools/` (e.g. `tools/case_RIGHT_up.stl`).

| # | Part | Qty | Actual file (correct hand) | Size (mm) | Profile | Orientation & notes |
|---|---|---|---|---|---|---|
| **1** | SuperMini cradle (LEFT) | 1 | `Scylla/files/MK2/supermini_cradle.stl` (=LEFT) | 30×8×34 | **process_parts_safe** | ✅ PRINTED (first assumed to be "R", turned out LEFT). Keep for the left half |
| **2** | SuperMini cradle (RIGHT) | 1 | mirror X of #1 | 30×8×34 | process_parts_safe | Not printed yet |
| **3** | Bottom plate (LEFT) | 1 | `Scylla/files/MK2/scylla_v3_36_plate_right.stl` (file "right" = LEFT) | 155×159×2 | **process_draft** | Flat; thin, 2mm. Rotate Y-up→Z-up before slicing |
| **4** | Bottom plate (RIGHT) | 1 | `Scylla/files/MK2/scylla_v3_36_plate_left.stl` (file "left" = RIGHT) | 155×159×2 | process_draft | Flat |
| **5** | Case (LEFT) | 1 | `Scylla/files/MK2/scylla_v3_36.stl` (=LEFT) | 159×163×58 | **process_parts_safe** | Open-bottom DOWN, keys up, ~58mm. Support ON. Print ~23h. (partially printed once) |
| **6** | Case (RIGHT) | 1 | mirror X → `tools/case_RIGHT_up.stl` | 159×163×58 | process_parts_safe | ⏳ Was printing when this was written. gcode: `out/case_RIGHT_safe.gcode` |

## Profile notes
- **process_parts** = normal quality (for the case: switch hole precision & fit matter).
- **process_parts_safe** = safe profile for small parts / overhangs (cradle).
- **process_draft** = fast, for the flat plates.
- **process_brim** / `--brim`: turn on a brim for thin / small parts (#1 to #4).
- filament_fast + machine_train = filament & machine profile (used by default by slice.py).

## Suggested order
1 (cradle, test) → 3,4 (plates, fast) → 5,6 (cases, long). Cradle first so the profile & first layer are verified before committing to a case print that takes many hours.

## Tenting stand: ✅ VERIFIED READY (2026-07-05), integrated cover, base stand, no wrist pad
**Integrated cover** (seal plate + hinge as ONE part), replaces the plain plates #3/#4. Verified:
- **Alignment to the case: outline IoU 0.9989** vs the official plate; flush all round in the overlay render (`tools/captures/tentfit-*.png`); protrusion only 0.2% = the hinge knuckles (functional).
- **Watertight** ✓ L+R (genus 14, vol 65.3cm³); 7 countersunk M4 screw holes in the official pattern; knuckle spacing 70.0mm; M4 bore horizontal when printed vertically.
- History: the old `final_cover_dl` was left in the **deployed pose (rotY −30°)** & turned out to be the RIGHT hand → un-posed (rotY −30.05, rotX −0.15), registered, unioned via manifold-3d (the OpenSCAD backend rejects the mesh), mirrored → LEFT.
- **SMOOTH pass (5 Jul):** the underside used to have a *ledge* (the repo's smaller intbottom plate hung 2mm below the seal) → laminated into a **uniform 4mm slab across the whole seal outline** (a copy of the seal shifted −1.6, inset 0.05mm so the boolean is clean) → the bottom face is ONE flat plane, the hinge gussets blend in smoothly. Genus −7 = the 7 old countersink voids got buried (harmless; the screw heads sit in the new countersinks on the bottom face). ⚠️ The plate is now ~3.7mm: use **M4 10mm bolts** into the case (8mm is a bit short).

Profile **`proc_tent`** (process_parts base: infill **25%**, brim 5mm, **support OFF**: the knuckle gussets are self-supporting, matching the repo photos). Fresh gcode in `out/` (5 Jul):

| Part | Qty | Est | gcode | Source STL | Orientation |
|---|---|---|---|---|---|
| Tent-cover LEFT | 1 | ~9h 26m | `out/tent_cover_LEFT.gcode` | `tools/tent/cover_tent_LEFT_vert.stl` | **vertical** (already baked into the STL; slice `--orient 0`) |
| Tent-cover RIGHT | 1 | ~9h 28m | `out/tent_cover_RIGHT.gcode` | `tools/tent/cover_tent_RIGHT_vert.stl` | vertical |
| Base bottom LEFT | 1 | ~2h 56m | `out/tent_bottom_LEFT.gcode` | `tools/tent/bottom.stl` | flat (auto) |
| Base bottom RIGHT | 1 | ~2h 57m | `out/tent_bottom_RIGHT.gcode` | `tools/tent/bottom_R.stl` | flat |
| Tenting arm | **2** | ~1h 47m /pc | `out/tent_arm.gcode` (print 2×) | `tools/tent/tenting-arm.stl` | flat (auto) |

Total ~30 hours. Flat-pose STLs (case frame, for preview/CAD): `tools/tent/cover_tent_LEFT.stl` / `_RIGHT.stl`; display assembly: `tools/assembled_LEFT.stl` / `_RIGHT.stl`. Hardware: 8× M4 bolts ≥14mm + 8× M4 nuts.

## Not queued yet (on purpose, later)
- Battery holder, cradle mount to the case: postponed until the keyboard is functional.
- Gel wrist pad: optional, parts in `tools/tent/wrist-pad-variant-parts/` (+12 M4, +2 gel pads).
- ~~6-thumb~~: aborted, using the 5-thumb default.

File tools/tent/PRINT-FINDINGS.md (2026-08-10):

# Tent Plate Print — Findings & Next Steps

## ✅✅ BREAKTHROUGH (2026-07-08/09) — IT PRINTS. Two root fixes.

After ~10 failed FLAT attempts in one session, the RIGHT plate printed **complete** (LEFT
printing after). Two things were wrong the whole time:

### 1. WRONG ORIENTATION — print VERTICAL, not flat.
The designer's readme says **"Print them vertically"** (see
`Charybdis/.../tenting-stand-with-wrist-pads/assets/print-position.png`): plate stands on its
long edge, anchored by a wide brim; the hinge knuckles become **gussets on the vertical wall**.
Printed **FLAT** (`*_print.stl`, body-down) the knuckles are thin tall tabs → they curl / nest
EVERY time (bare, with support, glue, any offset, Elegoo or our pipeline — all fail ~L4-5 or 76%).
**Use `plate_solid_{RIGHT,LEFT}_vert.stl` (147×14 footprint, 138mm tall).** Bonus: the vertical
footprint is a thin strip in the **bed CENTRE** (good adhesion) instead of spanning the warped
corners. Profile: **`proc_solid_supbrim`** (support@50° for pockets/knuckle overhangs + brim),
`--orient 0` (do NOT auto-orient — it lays it flat again), `--fan 255`, ~60% speed cap (tall part).

### 2. Z0 DRIFTS EVERY G28 (~±0.15mm) — use the NO-REHOME technique.
Root cause of the endless "ga nempel / hancur" first layers: the nozzle-contact home gives a
different Z0 each G28 (observed true Z0 ranged −1.31 … −1.52 in ONE session). Any injected offset
is wrong after the print re-homes. **Fix: home ONCE, paper-verify true Z0 at centre, then print
with G28 STRIPPED so it reuses that verified home.** Post-process the slice.py gcode:
- delete the `G28 ;home` line,
- replace `BED_MESH_CALIBRATE...` → `BED_MESH_PROFILE LOAD=6` (mesh must already be live),
- change the prime `G1 Z0 F300` → `G1 Z2 F300` (else it crashes with the offset applied).
Keep `homed_axes=xyz` valid between prints (don't power-cycle / don't re-home). Verify before each
start: `curl .../printer/objects/query?toolhead | ...homed_axes`.

**Offset math (don't confuse paper-Z with print-offset):** light paper drag at machineZ `m` ⇒
true Z0 `K = 0.1 − m`. Print offset for gap ~0.12 first layer ≈ `−(K)` (e.g. K=1.31 → ~−1.36).
**Glue raises the bed ~0.05-0.08mm → use a LESS negative offset** (with glue this session: −1.36).
Krak-krek mid-print = over-squish → babystep the offset UP live; curling/not-sticking = babystep DOWN.
**RE-GLUE ⇒ RE-PAPER-TEST, always.** Glue thickness varies wildly per application (observed true Z0
swung −1.23 (thick) … −1.34 (thin) just from re-gluing) — never reuse a prior offset after re-gluing.
30-sec routine: `SET_GCODE_OFFSET Z=0`, jog centre down to light paper drag at machineZ `m`, print
offset ≈ `m − 0.05` (a touch more squish for big flat parts / anchors). Big flat parts (base 130×130)
reach the warped corners → glue the 4 corners a bit heavier + use a brim; verified offset makes them hold.

### Assembly (fully documented — no need to invent a join):
- Plate → keyboard case: **8× M4 bolts 14mm + 8 nuts** (countersunk holes already in plate).
- Plate → tent base: **hinge knuckles + Ø4 pin** to `bottom.stl`, + **tenting-arm (35mm)** foot into
  base notches for the tent angle (17/21/25/29°, design ~24°). Hardware in SHOPPING-LIST.
- Next parts: LEFT plate (mirror ✓ made `plate_solid_LEFT_vert.stl`), then `bottom.stl` + `tenting-arm.stl`.

---

## Older notes (2026-07-07) — mostly SUPERSEDED by the breakthrough above

Marathon debug session on the Neptune 4 Pro printing the RIGHT tent plate (magnet mod).
This captures everything learned so tomorrow is a clean execution.

## ⚠️⚠️ CRITICAL: Z0 DRIFTS EVERY SESSION — paper-test EVERY power-on

The nozzle-contact home gives a **different Z0 each time the printer is power-cycled** (~0.05–0.10 mm).
This was the hidden cause of most "won't stick / balls on nozzle / menggumpal" failures — the injected
offset from a previous session is wrong after a reboot → nozzle prints too high → in air → clumps.

**MANDATORY each session before printing:** paper-test at bed center to find the touch point, then
`offset = touch_Z − 0.10`. Observed: 2026-07-06 touch −1.10 → offset **−1.20**; 2026-07-07 touch −1.20
→ offset **−1.30**. Procedure: `G28; BED_MESH_CLEAR; SET_GCODE_OFFSET Z=0; G1 X117 Y117; G1 Z-1.20`
(descend in 0.05 steps until light paper drag), then patch the gcode `SET_GCODE_OFFSET Z=<touch−0.10>`.
Homing needs a CLEAN nozzle tip (wipe first) or Z0 reads high.

## ✅ SOLVED

- **First-layer adhesion** — the #1 blocker all session. Fixed by **three things together**:
  0. **Paper-test the Z offset fresh EVERY session** (see the CRITICAL note above — this was the
     real recurring killer).
  1. **Degrease the bed** (IPA/alcohol or dish-soap+water, dry, don't touch surface after). PLA
     would not stick at a good gap until the bed was degreased — oils from all the handling.
  2. **Correct Z offset = −1.20** (NOT −1.11/−1.18 we used all night). Verified by **paper test
     at bed center**: light drag (~0.1 mm) at raw `G1 Z-1.10` (offset 0) ⇒ true Z0 correction
     ≈ 1.20. We were ~0.1 mm too high the whole time → gap ~0.29 instead of ~0.2 → not sticking
     / balling on nozzle. **Proof it works:** photo IMG_9028 — left/main body first layer is
     clean & stuck; only the right tabs failed (that's the extruder issue below, not adhesion).
- **Solid plate design** — the generic honeycomb `plate.3mf` is UNPRINTABLE (thin struts curl →
  stringy mess). Fixed by filling the honeycomb solid: `plate_solid_RIGHT_print.stl`
  (offset-close of the projection + extrude, magnet pockets re-cut). Body prints clean.
- **PLA temp** — 205 °C nozzle (NOT 220 → too hot, curls), bed 65 °C, fan max (255).
- **Bed trammed** — tilt 0.329 → 0.264 mm (4-corner paper tram). Mesh (profile 6) fresh.

## 🔧 IN PROGRESS — NOZZLE SWAP (confirmed needed, 2026-07-07)

After systematically ruling out EVERYTHING else, the nozzle still balls/clumps ("nyangkut / nempel
ke nozzle") → the **nozzle itself is worn/damaged** (dozens of blobs + needle pokes + cold pulls all
session). Ruled out this session: offset (paper-tested touch −1.20 → offset −1.30), 4-corner tram
(3 rounds — but tilt stayed **0.270**, because the bed is **WARPED/concave** (front+back edges dip
~0.18 mm), which tram can't fix — mesh compensates it during print, so tram wasn't the fix), fresh
mesh, degreased bed. Balling persisted → **swap the nozzle** (spare in the Neptune 4 box).

**Swap procedure:** heat 230 °C → unload filament → remove silicone sock → hold heater block with a
wrench + unscrew nozzle with the nozzle socket (CCW) → screw new nozzle in by hand, snug it **while
hot** (leak-free) → re-fit sock. **After swap: extrude-test (should flow straight/smooth) + RE-PAPER-
TEST the offset** (new nozzle = new tip height = new Z0). Was mid-swap when we stopped to rest.

## ⚠️ (was) extruder under-extrusion (partial clog) — superseded by nozzle swap above

Symptom: **"cetak cetek"** (extruder skipping/clicking) + right side of print bolong/blobby while
left side perfect = classic **under-extrusion / partial nozzle clog** (from all the blobs cleaned).
- **Fix: clean the nozzle internally** — unclog needle (from bed at ~205 °C) + cold pull. If it
  persists, swap the nozzle (cheap).
- After clean: verify with a clean extrusion (should flow smooth, no clicking).

## ⚠️ REMAINING — knuckle geometry (fails at ~76 %)

The plate's hinge knuckles print as a **forest of thin tall tabs** (Z-slice: 10–16 separate
islands above Z≈3). Bare → curl at 76 %. With support → support itself fails at 18 %. Vertical →
138 mm-tall 14 mm-thin wall = tippy + horizontal pockets. **NONE work.**
- **Next approach: SPLIT or REDESIGN.** Print the solid body alone (proven, prints to 100 % once
  adhesion is right), and either (a) a separate chunky hinge bracket bolted/glued on, or
  (b) redesign knuckles chunkier/shorter, or (c) simplify base attachment (bolt-on, no
  interleaving knuckles — tent angle is set by the arm notches anyway).

## KNOWN-GOOD RECIPE (use this tomorrow)

```
# 1. Cold-pull / needle-clean nozzle first. Degrease bed. Home with CLEAN nozzle.
# 2. Slice:
cd ~/Documents/neptune4-print-toolkit
python3 scripts/slice.py --stl /Users/arisjirat/keyboard-project/tools/tent/plate_solid_RIGHT_print.stl \
  --copies 1 --orient 0 --process profiles_local/proc_tent_lowstring.json \
  --filament profiles_local/filament_pla_cool.json --fan 255 --out /tmp/plate_solid_R.gcode
# 3. Patch (macOS sed needs -i.bak): nozzle 205, offset -1.20, bed 65:
sed -i.bak -e 's/ S220/ S205/g' -e 's/^M104 S220/M104 S205/' -e 's/^M109 S220/M109 S205/' \
  -e 's/SET_GCODE_OFFSET Z=-1.18/SET_GCODE_OFFSET Z=-1.20/' \
  -e 's/^M140 S60/M140 S65/' -e 's/^M190 S60/M190 S65/' /tmp/plate_solid_R.gcode
# 4. Send (upload+start via API — printer.py send times out; network flaky):
IP=192.168.1.164
curl -s --max-time 120 -F "file=@/tmp/plate_solid_R.gcode;filename=plate_solid_R.gcode" "http://$IP/server/files/upload"
curl -s -X POST "http://$IP/printer/print/start" -H "Content-Type: application/json" -d '{"filename":"plate_solid_R.gcode"}'
```

- **Live gap reads during print are confounded by mesh compensation** — don't trust `z+1.20`
  while printing (nozzle follows the mesh). Trust the paper test (mesh cleared) for the baseline,
  and your eyes for adhesion.
- If extruder skips again (over-squish) babystep UP; if not sticking babystep DOWN, live:
  `SET_GCODE_OFFSET Z=<val> MOVE=1` via Moonraker.

## FILES (all in tools/tent/)
- `plate_solid_RIGHT_print.stl` — solid plate, print-oriented (flat, body down), 5 magnet
  pockets ⌀8.3×1.5 blind + knuckles. **This is the one to print.**
- `plate_mag_RIGHT.stl` / `cover_magfeet_RIGHT.stl` — native-frame magnet-mod plate + cover.
- `plate_solid_RIGHT_vert.stl` — vertical orient (rejected, tippy).
- LEFT mirrors: `plate_mag_LEFT.stl`, `cover_magfeet_LEFT.stl` (need re-do for solid version).

## Magnet / hardware
- Magnet **⌀8×1.5 mm N52 ×10** (5 pairs/half), pockets drilled identical in plate+cover → auto-align.
- Rubber feet **⌀8** ×~16 (cover corners + base).
- Cover pockets are blind (no through-hole, no boss) — verified inner face flat.

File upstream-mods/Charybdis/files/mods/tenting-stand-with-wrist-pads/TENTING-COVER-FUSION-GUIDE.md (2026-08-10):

# Integrated Tenting Bottom-Cover — Fusion Build Guide

**Goal:** one bottom cover that (a) **seals our `scylla_v3_36` case** perfectly, (b) has the **tenting hinge + arm-attach** that mate the existing stand (`bottom.3mf` + `tenting-arm.3mf`), (c) sits **flat & seamless** when off the stand. Built in Fusion from the parametric source (raw-STL boolean can't do a clean bracket — hull gives a blob).

## Files
- **Parametric source:** `charybdis adjustable plate v3.f3d` (has the hinge + arm-attach + bracket already).
- **Our case bottom outline:** `Scylla/files/MK2/scylla_v3_36_plate_right.stl` (= the LEFT case bottom; mirror for right). This is the outline that seals our case.
- **Stand mates (don't modify):** `bottom.3mf` (base foot), `tenting-arm.3mf` (arm).

## Measured specs (all verified from the STLs this session)
> Reference frame = the shared **assembly frame** the 3mf files use (native, **Y = up**), where `bottom`+`plate`+`arm` are pre-assembled. Use these as the target positions on the cover.

| Feature | Position (assembly frame) | Notes |
|---|---|---|
| **Hinge pin** | **X=160.5, Y=5.0**, axis ∥ Z (spans Z≈−55…25) | cover hinges to base here; Ø~4.2mm (r≈2.1) |
| **Arm-attach boss** | **X=99.5, Y=40** (Y=43 on source), axis ∥ Z | arm top pivot bolts here; Ø~4.2mm |
| **Base notch rack (pin-lock)** | Y=7, X ∈ {70, 80, 90, 100} | 4 discrete tent angles |
| **Design tent angle** | **≈24–26°** (plate face normal 24° from vertical) | |
| **Arm length** | **35 mm** (foot↔top pivot) | foot in base notch, top on cover |
| Arm foot (design) | X=95, Y=4.5 | sits in a base notch |

Frame-independent relationships (safest to trust):
- **Hinge → arm-attach:** ~**70 mm** apart; arm-attach is **~61 mm inward** (toward case centre) and **~35 mm up** from the hinge pin.
- Pin-lock tent angles ≈ **17° / 21° / 25° / 29°** (X70/80/90/100 notches). Design ≈ 24°.

## Approach (recommended: edit the parametric source)
The source `charybdis adjustable plate v3.f3d` already generated the working `left-case-bottom-scylla` (correct hinge+arm+bracket) — it's just built on a **different Scylla outline**. So **swap the plate outline to ours, keep the hinge/arm/bracket features.**

1. Open `charybdis adjustable plate v3.f3d` in Fusion. Inspect the timeline — find the **plate body / base sketch** (the flat case-outline part) vs the **hinge knuckles**, **arm-attach boss**, and **bracket** features.
2. **Import our outline:** Insert → Mesh → `scylla_v3_36_plate_right.stl`. (Mirror if you're doing the right hand.) Convert/trace its perimeter into a sketch (Create Sketch on its plane, project the outline). This is the sealing outline.
3. **Replace the plate profile:** edit the plate base sketch so its outline = our traced outline (delete the old profile, use ours). Keep the plate thickness (~2–3 mm) and the **mounting-hole pattern that matches our case** (from `scylla_v3_36_plate_right.stl` — it already has them). Line the plate up so its holes match our case's bottom bosses.
4. **Keep the bracket + hinge + arm features** — they hang off the plate's hinge edge. Verify (or set) their positions to the specs above: hinge pin along the hinge edge, arm-attach ~61 mm inward / ~35 mm up. The bracket = gusset walls dropping from the plate edge down to the knuckle bar (spans the ~30 mm to base level).
5. If the hinge/arm don't auto-follow the new outline, reposition them: put the **knuckle bar on the plate's inner/back edge** so, when the cover is at 24° tent, the knuckles reach the base's hinge and the arm reaches a notch (arm length 35 mm).

## Alt approach (if the source is hard to parametrize)
Combine in Fusion instead of parametrizing:
1. Insert our plate STL (sealing outline) **and** `left-case-bottom-scylla.stl`.
2. From the remix, **keep only the hinge knuckles + arm-attach boss + bracket gussets** (delete its plate body).
3. Align the kept bracket to our plate's hinge edge (match the hinge-pin & arm-attach specs above).
4. **Combine (join)** our plate + the bracket into one solid. Add fillets at the bracket/plate join for strength.

## Flat-seamless requirement (user-approved)
So the cover sits **flat & closed** when used without the stand:
- Make the **hinge knuckles flush** with (or recessed into) the plate's bottom plane, OR
- Add a thin **flat skid** on the underside so the part rests flat (knuckles not proud).
- Goal: off the stand it looks like a normal sealed keyboard bottom.

## Verify before export
- [ ] Cover outline = our case bottom (seals `scylla_v3_36`, holes match).
- [ ] Hinge knuckles interleave with `bottom.3mf`'s knuckles on the same Ø4 pin.
- [ ] Arm-attach Ø4 reaches `tenting-arm.3mf` top; foot reaches base notches (arm 35 mm).
- [ ] At 0°/flat the underside sits flat (skid/flush hinge).
- [ ] Watertight (Fusion solid).

## After
- Export STL. **Print orientation:** cover flat / bracket per `assets/print-position.png` (hinge vertical for strength if needed).
- Hardware: **M4 bolts ≥14mm ×8 + M4 nuts ×8** (already in SHOPPING-LIST).
- Mirror for the other hand.

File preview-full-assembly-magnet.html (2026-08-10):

# 🧲 MAGNET — tent tanpa baut + kaki karet

Joint baut → 5 pasang magnet ⌀8×1.5 N52 (rata, flush, tanpa boss). Cover keyboard juga dapat 4 recess kaki karet ⌀8 buat mode standalone (tent dilepas).

💥 Angkat keyboard (lihat marker) 0

Magnet: ⌀8×1.5mm N52, 5 pasang (magnet↔magnet, muka ketemu muka). Pocket dibor identik di plat & cover → auto-align.
Plat pocket ⌀8.3×1.5 blind (plat 3mm → floor 1.5). Cover pocket ⌀8.3×1.5 blind (floor 0.5, TANPA boss) → sisi dalam keyboard RATA, magnet nggak tembus.
Magnet dikecilin ke ⌀8 biar cukup jauh dari tepi (frame plat sempit): margin cover-edge 3–4.5mm.
Kaki karet: 4 recess ⌀8×1 di sudut cover (mode standalone, tent dilepas) — ukuran sama kayak base.

Geser Explode buat angkat keyboard & lihat 5 magnet biru di antara plat & cover. TODO: mirror KIRI + validasi + polarity glue.

Drag=putar · scroll=zoom · geser Explode buat pisahin keyboard dari tent.

loading…

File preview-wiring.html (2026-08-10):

# ArkButton

handwired split · 6×5 matrix · col2row · nice!nano v2

Skema handwiring per tangan. Garis berwarna = bus kabel asli keyboardmu (kolom & baris). Tiap switch: satu kaki ke bus kolom, kaki lain lewat dioda ke bus baris. Baris 4 = 5 thumb.

sisi solder · mirror sisi atas

## Matrix

29 key/tangan (24 jari + 5 thumb) · dioda 1N4148

tangan kiri — central (USB/BLE ke Mac)

tangan kanan — peripheral (BLE ke kiri) · pin identik, beda keycap

## Controller & Power

HwThinker Pro Micro nRF52840 · nomor = silkscreen board

bus kolom/baris → pin bernomor · baterai → B+/B− · slide switch di jalur B+ · LED indikator di pad 002

## Referensi

### Warna kabel

Warna diambil dari kabel fisikmu (terkonfirmasi). kuning & merah dipakai 2× — beda kabel; label C/R yang membedakan.

### Aturan

Band dioda (garis) menghadap bus BARIS. Terbalik → key mati atau ghosting.

col2row: kolom di-drive, baris di-baca. Tap bus boleh dari titik mana pun (satu bus = satu node).

022 terbukti MATI sebagai GPIO di board ini (QSPI flash clone) → C1 orange dipindah ke 031 (P0.31). 020/024 sebelahnya normal.

Tangan KANAN = mirror. Pin kiri & kanan identik & urutan sama, tapi PCB kanan cermin → kolomnya kebalik. Dikoreksi di firmware (right.overlay membalik col-gpios + col-offset=6), bukan di wiring. Jangan disolder ulang.

Clock fix (wajib clone): HwThinker Pro Micro nRF52840 tanpa kristal 32.768kHz → split link timeout, kanan mati. Diperbaiki di .conf dengan K32SRC_RC=y.

## Indikator baterai

1 LED per tangan · P0.02 · pola kedip

### Pola kedip

< 30% → kedip 2× per detik (nyala ~90ms, jeda ~410ms), diulang tiap 60 detik biar nggak berisik & nggak boros.

< 10% → pola sama tapi diulang tiap 20 detik.

Cek manual — tekan kombo &bat_ind: jumlah kedipan = level. 4 = >75%, 3 = >50%, 2 = >30%, 1 = kritis.

Boot — 1 kedip panjang saat board nyala = tanda hidup.

Tiap half nunjukin baterainya sendiri, nggak lewat link BLE — jadi tetap jalan walau split lagi putus.

### Komponen & catatan

LED 3mm/5mm biasa: hijau di kiri, kuning di kanan. Resistor 680Ω (≈2mA — aman untuk drive standar GPIO nRF52840 dan tetap terang di dalam case).

Kaki panjang = anoda → ke resistor/GPIO. Kaki pendek + sisi rata di badan LED = katoda → GND. Kebalik = LED nggak nyala (tidak rusak).

Pad 002 (P0.02) dipilih karena bebas dan aman — bukan pin QSPI seperti 020–024. Pin ini sama untuk kedua half, jadi wiring kiri & kanan identik.

Nanti kalau LED RGB sudah dibeli: LED ini tinggal dipindah jadi salah satu channel, jalur 002 tetap dipakai.

## Urutan

1. Pasang 30 switch. Balik keyboard — mode sisi solder sudah di-mirror sesuai yang kamu lihat.
2. Bus kolom (6): satu kawat per kolom, sambung kaki-1 semua switch sekolom, ujung ke pin kolom.
3. Dioda (30): kaki-2 tiap switch → 1N4148, band ke arah bus baris.
4. Bus baris (5): sambung ujung dioda sebaris, ujung ke pin baris. Baris 4 = 5 thumb.
5. Baterai → B+/B− (via slide switch di B+). Cek continuity sebelum tutup case.
6. LED indikator (2 kabel/tangan): pad 002 → resistor 680Ω → kaki panjang LED (anoda); kaki pendek (katoda) → GND. Kiri hijau, kanan kuning.

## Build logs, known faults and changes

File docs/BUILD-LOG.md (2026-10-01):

# Build log

From a pile of printed parts to a working wireless split, in about four weeks.
Dates are local time (WIB). Details live in the linked notes, this page is the
timeline.

| Date | What happened |
|---|---|
| Nov 2024 | [Previous build](#previous-build-nov-2024): a handwired Dactyl |
| 27 Jun 2026 | Project start |
| 30 Jun 2026 | Handedness correction: the upstream STL names are mirrored |
| 5 Jul 2026 | Integrated tent cover verified against the official plate |
| 7 to 9 Jul 2026 | Tent plate print failures, then the two fixes that made it print |
| 13 Jul 2026 | [Parts on the bench](#parts-and-bench-13-jul-2026), soldering starts |
| 14 Jul 2026 | [First half on the tenting stand](#on-the-tenting-stand-14-jul-2026) |
| 16 Jul 2026 | [Both matrices wired](#matrix-wired-16-jul-2026) |
| 19 Jul 2026 | Keymap remapped, clone-board firmware findings written down |
| 25 Jul 2026 | [Final setup](#final-setup-25-jul-2026) |

## Printing (27 Jun to 9 Jul 2026)

- **Handedness.** The Scylla files in the upstream repo are named the wrong way
  round: `scylla_v3_36.stl` is the left case and `..._plate_right.stl` is the
  left plate. Verified by render comparison and plate IoU. The corrected table
  is in [`PRINT-QUEUE.md`](../PRINT-QUEUE.md).
- **Tent cover.** The seal plate and the hinge were fused into one part that
  replaces the plain bottom plate. Outline IoU against the official plate:
  0.9989.
- **Tent plate.** About ten failed flat prints in one session. Two root causes:
  the plate has to be printed vertically, and Z0 drifts by about ±0.15 mm on
  every `G28`, so the fix was to home once, paper-verify, and print with the
  re-home stripped from the gcode. Full write-up in
  [`tools/tent/PRINT-FINDINGS.md`](../tools/tent/PRINT-FINDINGS.md).

## Parts and bench (13 Jul 2026)

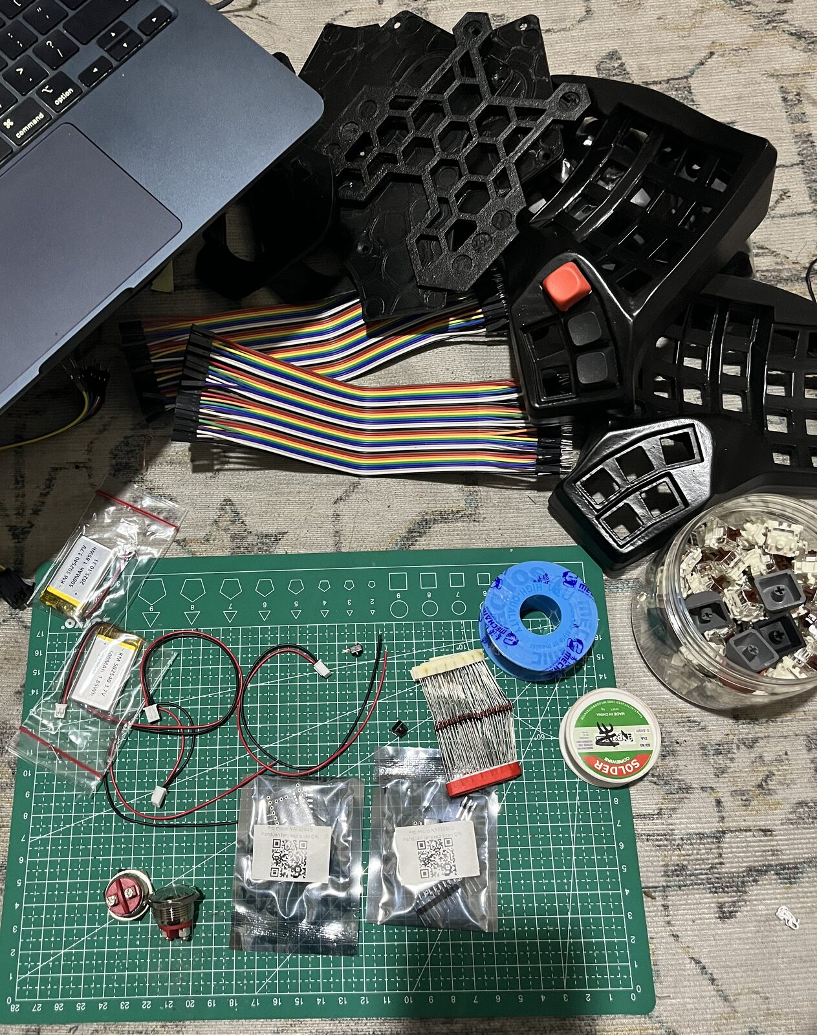
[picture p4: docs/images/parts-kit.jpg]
Printed cases, tent plates, diodes, batteries, controllers and switches laid out


Both cases and the tenting stand parts printed, next to the electronics: two
nRF52840 controllers, two LiPo cells, 1N4148 diodes, jumper ribbon and a jar of
switches. Sourcing notes are in [`SHOPPING-LIST.md`](../SHOPPING-LIST.md).

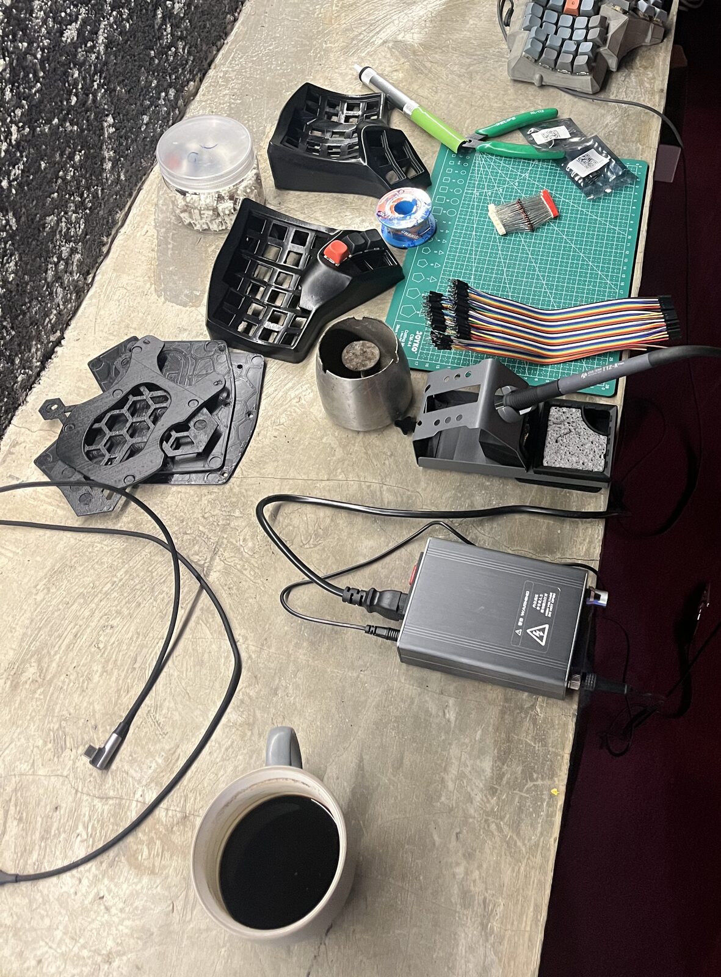
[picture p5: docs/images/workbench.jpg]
Workbench with the soldering station, both cases and the tent plates


## On the tenting stand (14 Jul 2026)

One half mounted on the tenting stand, seen from the side

First half bolted to its tenting stand: plate hinged to the base, the arm
setting the angle. The grey keyboard behind it is the previous build.

## Matrix wired (16 Jul 2026)

Both halves open, switches soldered with diodes and coloured row and column wires

Both halves wired: one diode per switch, soldered straight to the switch pins,
no hotswap sockets and no PCB. The wiring sheet is `preview-wiring.html`.

## Firmware (19 Jul 2026)

Two findings specific to the HwThinker clone boards, both fixed in
[charybdis-wireless-zmk](https://github.com/arisros/charybdis-wireless-zmk):

- No 32.768 kHz crystal, so the BLE split link timed out and the right hand was
  dead until `CONFIG_CLOCK_CONTROL_NRF_K32SRC_RC=y` forced the internal RC
  oscillator.
- `P0.22` is not usable as GPIO on this board (QSPI flash), so Col1 moved to
  `P0.31`.

The base layer was remapped the same day (thumbs, pinky and Home), see
`preview-keymap.html`.

## Final setup (25 Jul 2026)

Both halves on their tenting stands either side of a closed laptop

## Previous build (Nov 2024)

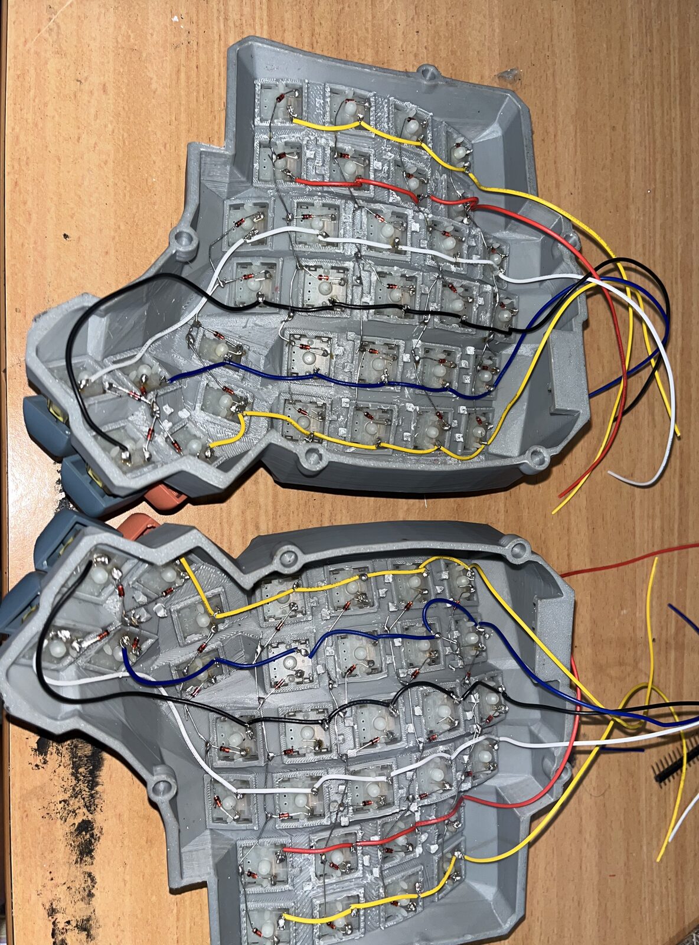
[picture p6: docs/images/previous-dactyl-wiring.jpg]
Underside of a grey handwired Dactyl, both halves


The keyboard this one replaces: a handwired Dactyl. It shows up in the
background of a few of the photos above.

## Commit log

2026-07-18 docs: keymap preview + wiring/shopping sync (58 keys, 5 thumb, HwThinker, clock/mirror findings)
    - add preview-keymap.html (current 4-layer keymap, style matches preview-wiring)
    - preview-wiring.html: HwThinker label, mirror + clock-fix notes, 29 key/hand
    - SHOPPING-LIST.md/.csv: HwThinker Pro Micro primary, clock fix note, 58 keys
    [SHOPPING-LIST.csv]
2026-08-10 chore: add .gitignore and untrack vendored clones + generated artifacts
    Upstream clones (Charybdis, Cosmos-Keyboards, Scylla, dactyl-manuform,
    STL-to-OpenSCAD-Converter, zmk-studio) and the own ZMK config repo each
    have their own remote, so they no longer sit in this index. Generated
    geometry (*.stl/*.gcode/*.uf2), OpenSCAD renders and tools/captures are
    regenerable and now ignored. Files stay on disk, only the index changes.
    [block.stl, block_panel.stl, bracket.stl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]
2026-08-10 feat(tent): OpenSCAD sources for the tenting mechanism + print findings
    Working set behind the tenting cover/hinge/arm iterations: graft and
    bracket experiments, flat vs vertical plate variants, magnet mount under
    tent/mag, plus names.txt. PRINT-FINDINGS.md records the two fixes that
    made the plate print (vertical orientation + brim) after ~10 flat fails.
    capture.mjs gains the matching capture sets (tent, Scylla, Charybdis
    6-thumb, magnet assembly).
    [_adjchk.scad, _asm.scad, _asm2.scad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]
2026-08-10 feat: print queue, three.js previews and firmware flash helpers
    PRINT-QUEUE.md is the Neptune 4 Pro queue for the Scylla wireless build,
    including the verified handedness correction (repo file names are
    mirrored). Adds preview.html, preview-tenting.html and
    preview-full-assembly-magnet.html viewers, updates preview-wiring.html,
    and keeps the firmware/flash + firmware/kbstatus scripts (the .uf2
    binaries stay ignored, they are CI output).
2026-08-10 feat: vendor our sources out of the gitignored upstream clones
    userconfig.ts, mesh-split.mjs and the gen-*.ts exporters generate every STL in
    cosmos/, the plug/6-thumb CAD drives the Charybdis mods, and the Scylla and
    dactyl scad files back the cradle and tent stand — yet all of them only existed
    inside clones this repo ignores, so none were backed up anywhere.
    upstream-mods/ mirrors each file at its path inside the clone. fetch-upstream.sh
    clones the five upstream repos at their pinned commits and copies the mods in;
    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
    [_diag_axes.scad, charybdis_6thumb.scad, export_parts.scad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]
2026-08-10 docs: add root README; make scad and firmware paths machine-independent
    README explains the build, the directory map, the fetch-upstream setup step and
    where the .uf2 files come from. The tent scad files imported STLs by absolute
    /Users/arisjirat path — now relative to the scad file, which is how OpenSCAD
    resolves them anyway. firmware/flash derives its directory from $0 and points at
    the ZMK Actions artifact when a .uf2 is missing. Drops empty tools/tent/names.txt.
    [_asmchk.scad, _cover_mod.scad, _mL.scad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]
2026-10-01 docs: translate print queue and shopping list to english
    - content, checkboxes and every URL unchanged
    - both marked as historical working notes, the build finished in July 2026
    [SHOPPING-LIST.csv]
